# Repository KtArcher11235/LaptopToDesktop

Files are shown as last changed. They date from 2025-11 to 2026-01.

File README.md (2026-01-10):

# LaptopToDesktop
Making a desktop from a laptop<br>


<br>

I had an old <a href="https://www.hp.com/us-en/shop/pdp/hp-laptop-17z-ca200-8yk85av-1">laptop</a>, but it no longer worked, so I decided to turn it into a desktop. This will let you turn any old motherboard from a laptop, into a desktop.
<br>The original laptop is no longer made but you can probably find one on ebay, however, I've made it so that you can just put any board into it.
<br>
<br>
The .step and .stl print files are in /CAD
you can find the onshape <a href="https://cad.onshape.com/documents/119253da891d8e3245ef7dcf/w/4ce91ff017f0e0c2d6eeb039/e/43b8a0fbfd1931149223f89a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">here</a> 
## Printing
I printed out of pla, 0.3 mm layer height, 5% gyroid infill on my prusa mk3s+ from prusa slicer. Smallest side down (because my printer can't do long distances)<br>

<br>
glue can hold the parts together, I used gorilla glue <br>
For the peg:<br>
<br>
I printed at 0.3 mm layer height at 100% infill. It probably works other ways too. You can print a whole bunch at once.
everything else isn't important.
<br><br>
## Assembly 
once it prints you can glue the frame together and the pegs into place. Make sure to also cut holes for the ports.
The laptop motherboard can then just screw into the pegs.
## Special parts
The wifi chip can either go into a normal peg or you can also edit the .step peg. It is the same with the ssd. Most other stuff can get glued.
## Customize
It's open source, go crazy.
## BOM
| item | aprox. price | |
|---|---|---|
| >1kg 3d printer plastic | ~20 | |
| - all of the frame parts | | |
| -enough pegs for your laptop | | |
| laptop (used preferably) | ~ 0 -2000$ | I used https://www.hp.com/us-en/shop/pdp/hp-laptop-17z-ca200-8yk85av-1 |
| -screws that came in laptop to hold board to peg | | |
| Glue | ~20 ish | I used https://gorillatough.com/product/gorilla-clear-grip/ |
| Acrylic sheet | ~20 ish | I got it from lowes

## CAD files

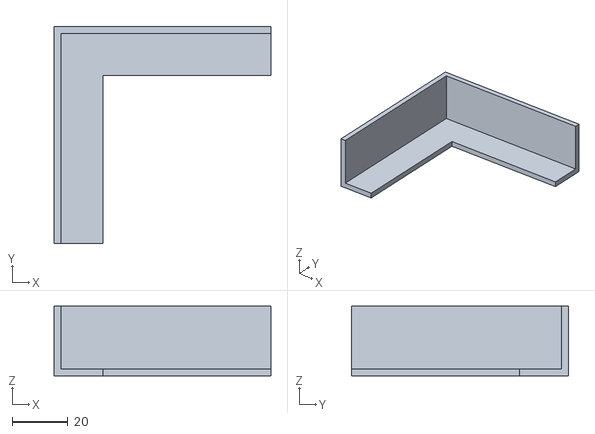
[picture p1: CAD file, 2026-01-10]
CAD/plastic holder.stl
77.5 x 77.5 x 25.0

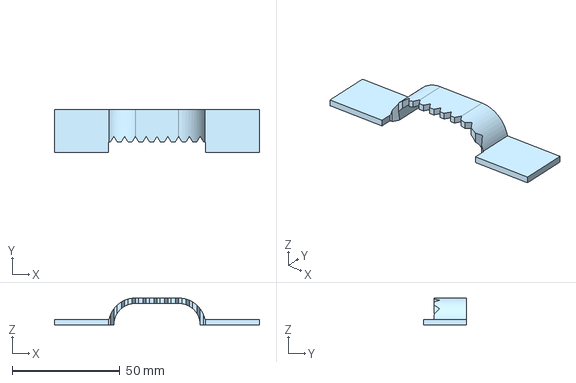
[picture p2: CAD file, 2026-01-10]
CAD/hook.step
95.0 x 20.0 x 12.5 mm

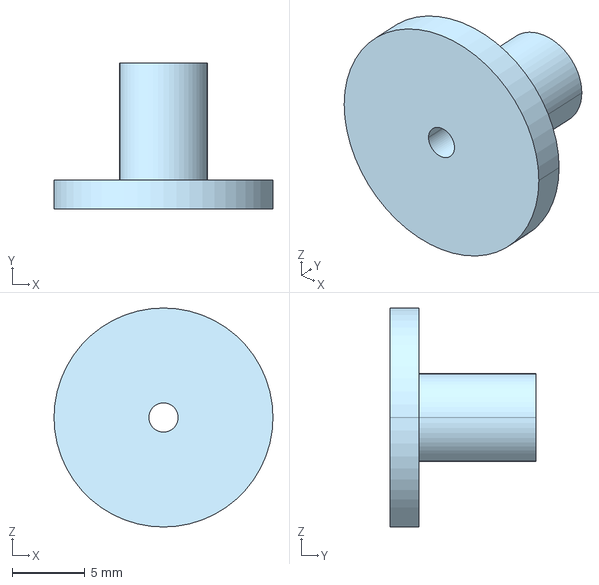
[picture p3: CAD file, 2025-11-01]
CAD/peg.step
15.0 x 10.0 x 15.0 mm

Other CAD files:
CAD/bracket.step
CAD/hook.stl
CAD/peg.stl

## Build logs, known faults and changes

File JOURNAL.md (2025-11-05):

<!--
  ===================    !!READ THIS NOTICE!!   ====================
  DO NOT edit this file manually. Your changes WILL BE OVERWRITTEN!
  This journal is auto generated and updated by Hack Club Blueprint.
  To edit this file, please edit your journal entries on Blueprint.
  ==================================================================
-->

## 10/26/2025 2:27 PM - testing  


made the basic cad for the box and set it 3d printing
decided that I'm going to make this configurable to work with any laptop
and just cut the plastic myself

## 10/26/2025 2:38 PM - got the computer part  


tore apart an old HP 17z-ca200 to get the electronics inside
it doesn't have a bios battery so it will just have to stay plugged in
i'll probably wire up a usb hub that i have so it can be more durable  

## 10/26/2025 9 PM - printing   

started printing the case for the new computer. 
Decided to use a pegs-based system to mount he board with the screws that it came with.
will need to do a lot of gluing.

## 10/31/2025 - glued  

finished printing
tried hot glue but it dried too fast
used gorilla glue and it worked (the plastic was pla)
waited for it to dry (not included in time)
got the extremely sophisticated clamps off (a wad of tape)



## 11/2/2025 - cuting  

cut the frame so that it had the holes for ports.
I chose to make it a solid frame that the user had to cut in order to make it work with more laptops than mine.
Caded the pegs for the screws to hole the board to the frame, I also made them glue-able so that they would work with any board.


## 11/4/2025 8 PM - finished  

Got it glued together, and put the board in.
It is pretty bad, but it works.
the ssd is glued in, but that is because it lacks a longer cable and it wouldn't fit anywhere.
It boots I think



## 11/4/2025 9 PM - did the repo  

I made the README and organized the files. Added sections about Printing, Assembly, and the BOM. 
The BOM is really just a laptop and 3d filament. I've included both .step and .stl for printability. Also I included the link to the onshape.


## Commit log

2025-10-31 Update README with download and Onshape links
    Added download link for .STL print files and updated Onshape link.
2025-10-31 Change download link for .STL files
    Updated download link for .STL print files.
2025-10-31 Replace STEP file with ZIP archive
    [STEP_CAD.step]
2025-10-31 Enhance README with printing info and laptop details
    Added printing details and clarified laptop modification instructions.
2025-10-31 Update printing instructions and add image
    Added details about printing orientation and glue used.
2025-11-03 Move CAD files into CAD directory
    [peg.step, peg.stl]
2025-11-03 Update README with printing details and images
2025-11-03 Update printing instructions in README
    Added information about printing multiple items at once.
2025-11-03 Rename BOM CSV file and fix line endings
    Renamed 'laptop to desktop bom - Sheet1.csv' to 'BOM.csv' and updated line endings to use LF consistently. No content changes to the BOM data.
    [BOM.csv, laptop to desktop bom - Sheet1.csv]
2025-11-05 Revise file download links and add CAD directory info
    Updated links for .STL and .STEP files and added CAD directory information.
2025-11-05 Enhance README with project details and instructions
    Updated README with additional details about the project, including assembly instructions and printing specifications.
2025-11-05 Add BOM section to README
    Added a Bill of Materials (BOM) section with item prices.
2025-11-05 Update price for 3D printer plastic in README
2025-11-05 Modify BOM.csv with updated prices and link
    Updated prices for 3D printer plastic and added a link for the laptop.
    [BOM.csv]
2026-01-10 Update BOM.csv with new materials and formatting
    Added acrylic sheet to BOM and fixed formatting for Glue entry.
    [BOM.csv]
2026-01-10 Fix formatting in BOM.csv
    [BOM.csv]
2026-01-10 Fix formatting issue in BOM.csv
    Removed extra comma from Glue entry in BOM.csv
    [BOM.csv]
2026-01-10 add new cad
    [bracket.step, hook.step, hook.stl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]
